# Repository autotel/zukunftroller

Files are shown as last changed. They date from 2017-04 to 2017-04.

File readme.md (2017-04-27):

#Building Controller shematic
##Pin allocation

Inputs/ outputs requeridos
```
                                1: 25 botones en circulo
                                  |  2: 11 botones de modo
                                  |  |  3: 2 terminales de led independientes
                                  |  |  |  4: 11 terminales independientes de led
                                  |  |  |  |  5: 3 terminales para controlar dos pantallas (clock,data,?)
                                  |  |  |  |  |  6: 12 encoder 12 estados
                                  |  |  |  |  |  |  7: 1 botón reset (usaremos el pin reset de arduino)
                                  |  |  |  |  |  |  |  8: 4 dos encoders de parámetro
                                  |  |  |  |  |  |  |  |  9: 2 pines display oLed sobre I2C
                                  |  |  |  |  |  |  |  |  |  10: 1 Midi out
                                  |  |  |  |  |  |  |  |  |  |  11: 1 Midi o serial in (para acoplar teclado melódico, que es un desarrollo aparte)
Pines de los multiplexores -------|--|--|--|--|--|--|--|--|--|--| --------------------------------------------------------------------------
                                  |  |  |  |  |  |  |  |  |  |  |  12: 8 MUX address
                                  |  |  |  |  |  |  |  |  |  |  |  |  13: 2 MUX Common
                                  |  |  |  |  |  |  |  |  |  |  |  |  |  14: 3 Shift register
... van conectados al pin...------|--|--|--|--|--|--|--|--|--|--|--|--|--|---------------------------------------------------------------------
                                  |  |  |  |  |  |  |  |  |  |  |  |  |  |    Total usado:
Directo arduino (18,+1 Tx)--------|--|--|--|--|--|--|--|--|--|--|--| 8| 2|--  | 10/18
Terminal Reset (1)----------------|--|--|--|--|--|--| 1|--|--|--|--|--|--|--  | 1/1
Multiplexor Directo (n=32)--------|--|--|--|--| 3|--|--| 4| 2| 1|--|--|--| 3  | 13/32
Multiplexor en Matrix (256-n^2)---|25|11|--|--|--|12|--|--|--|--|--|--|--|--  | 48/(256-13^2)
Puerto serial in Arduino (1)------|--|--|--|--|--|--|--|--|--|--| 1|--|--|--  | 1/1
Shift register (8 o 16)-----------|--|--| 2|11|--|--|--|--|--|--|--|--|--|--  | 13/16
```

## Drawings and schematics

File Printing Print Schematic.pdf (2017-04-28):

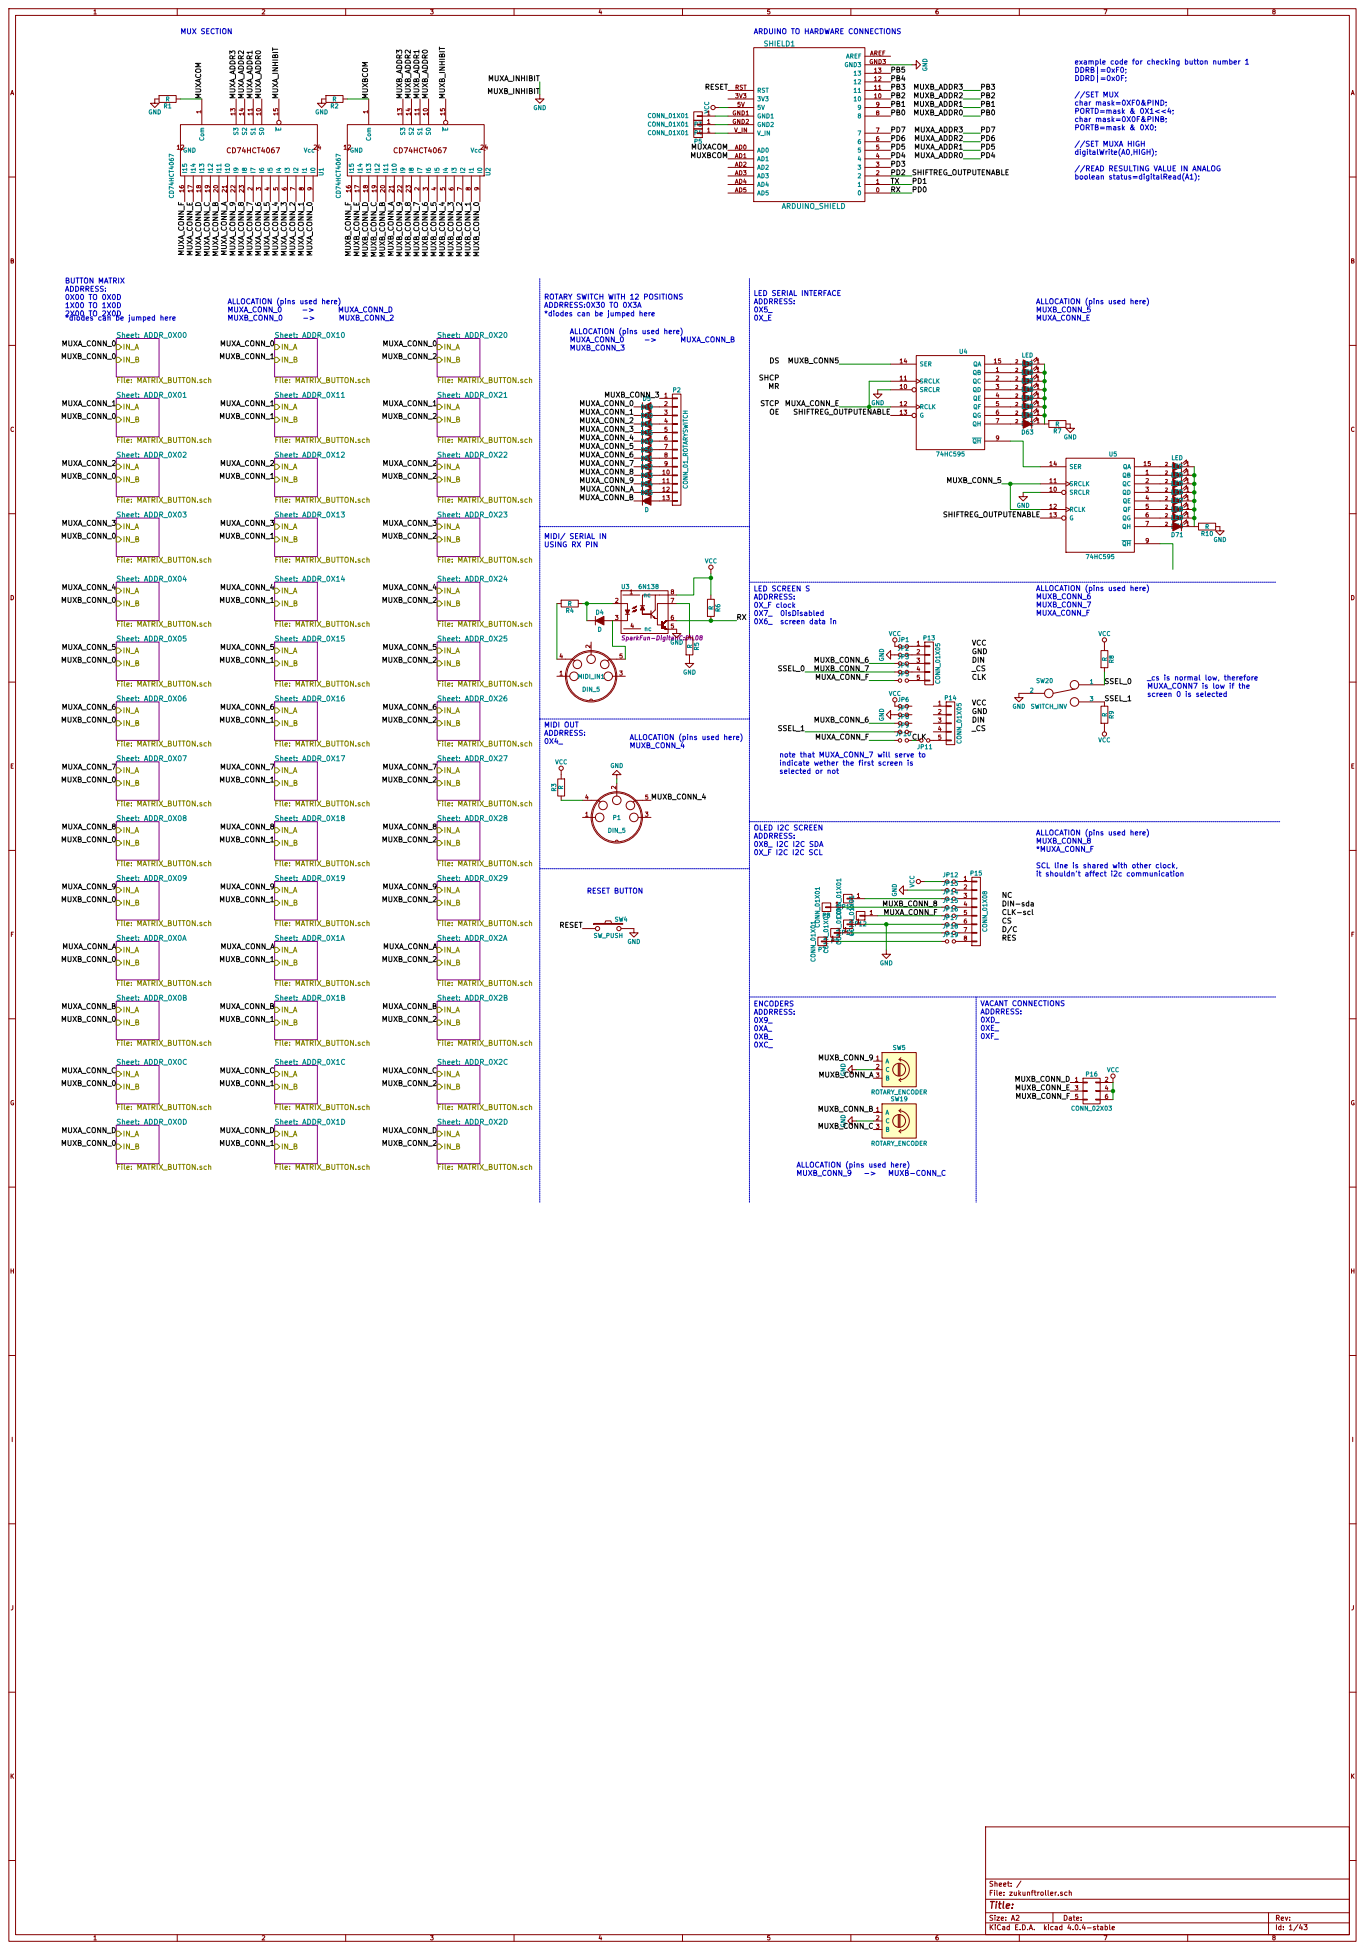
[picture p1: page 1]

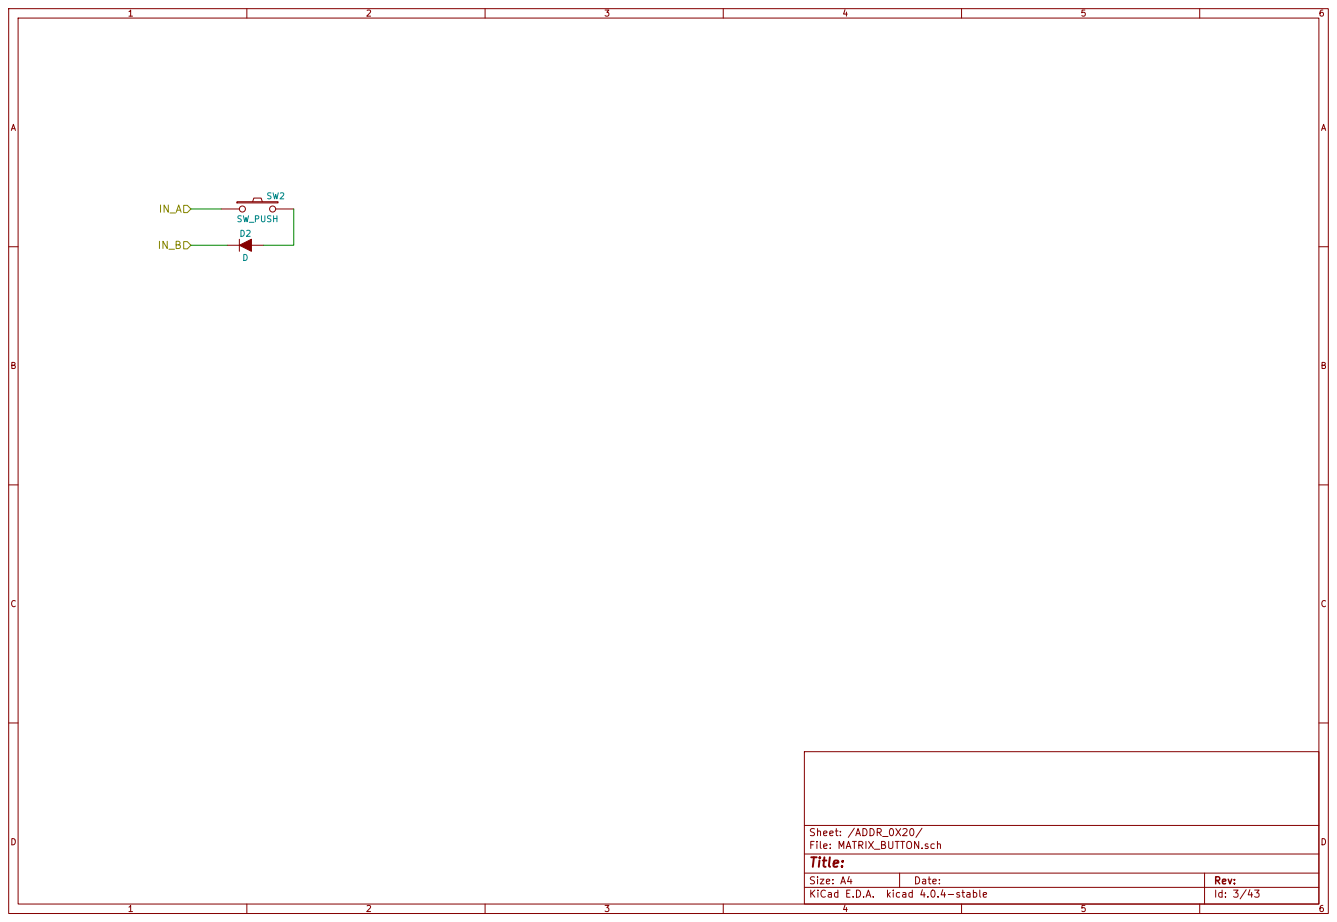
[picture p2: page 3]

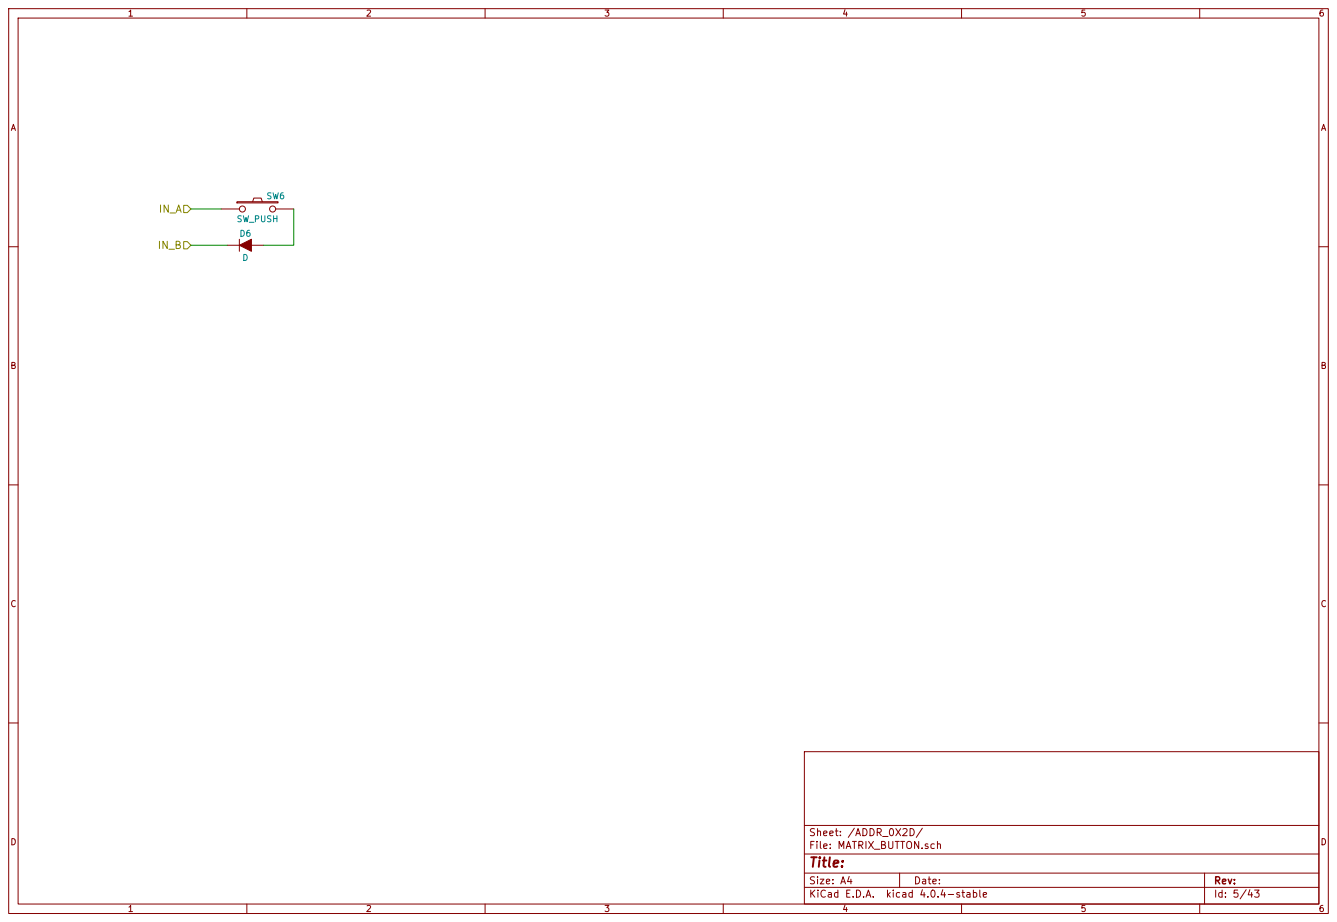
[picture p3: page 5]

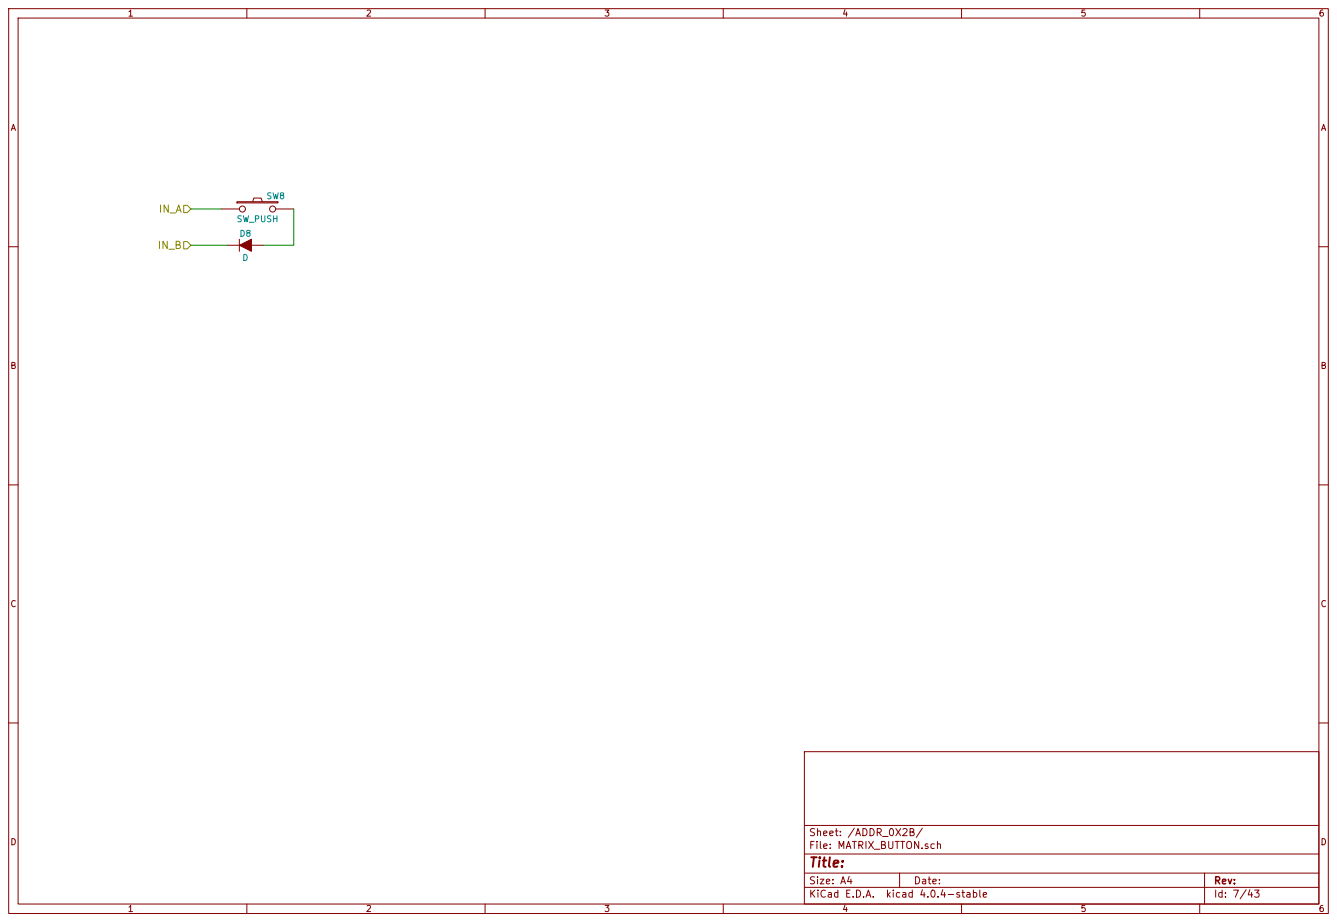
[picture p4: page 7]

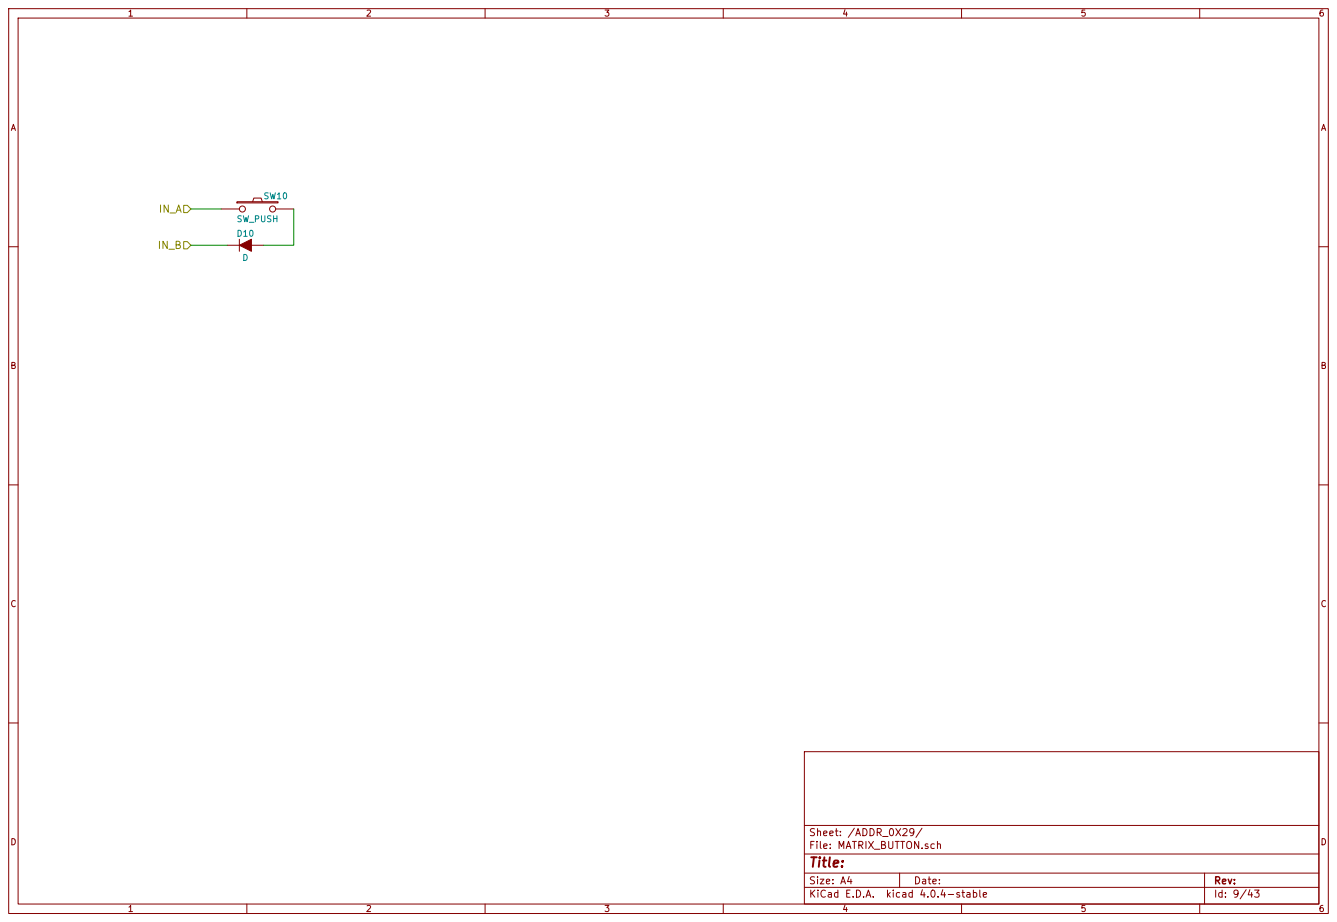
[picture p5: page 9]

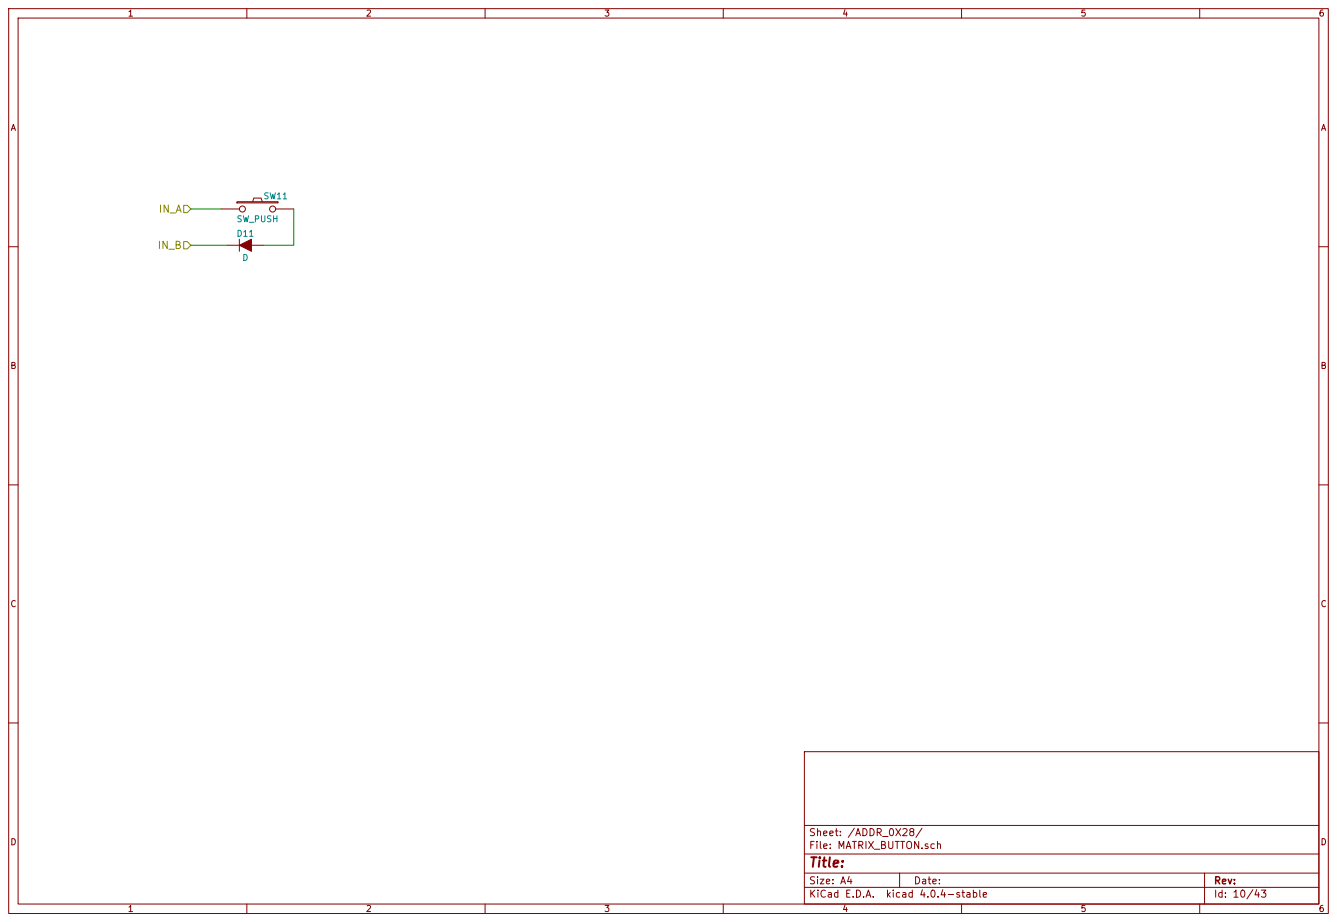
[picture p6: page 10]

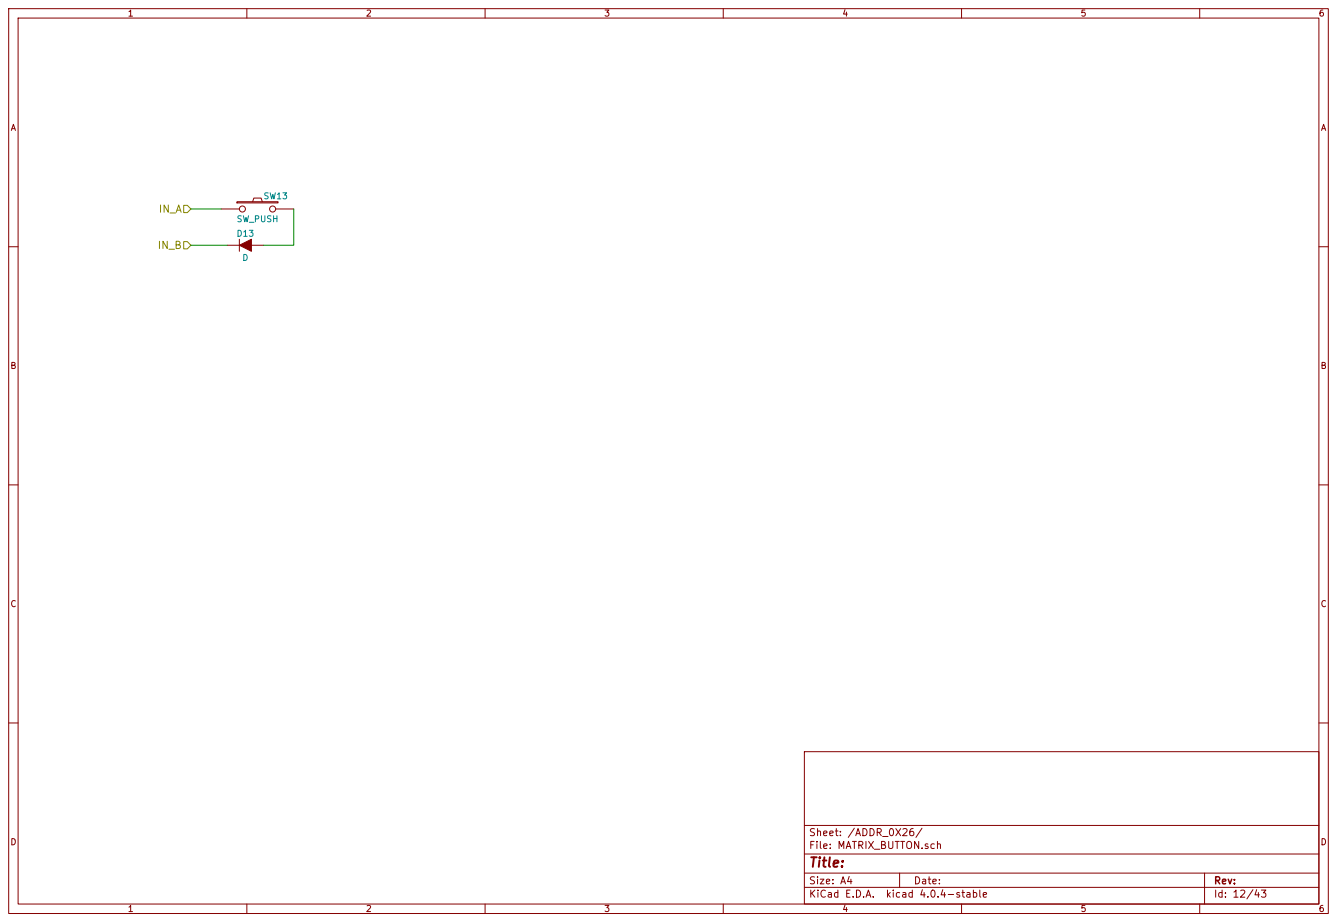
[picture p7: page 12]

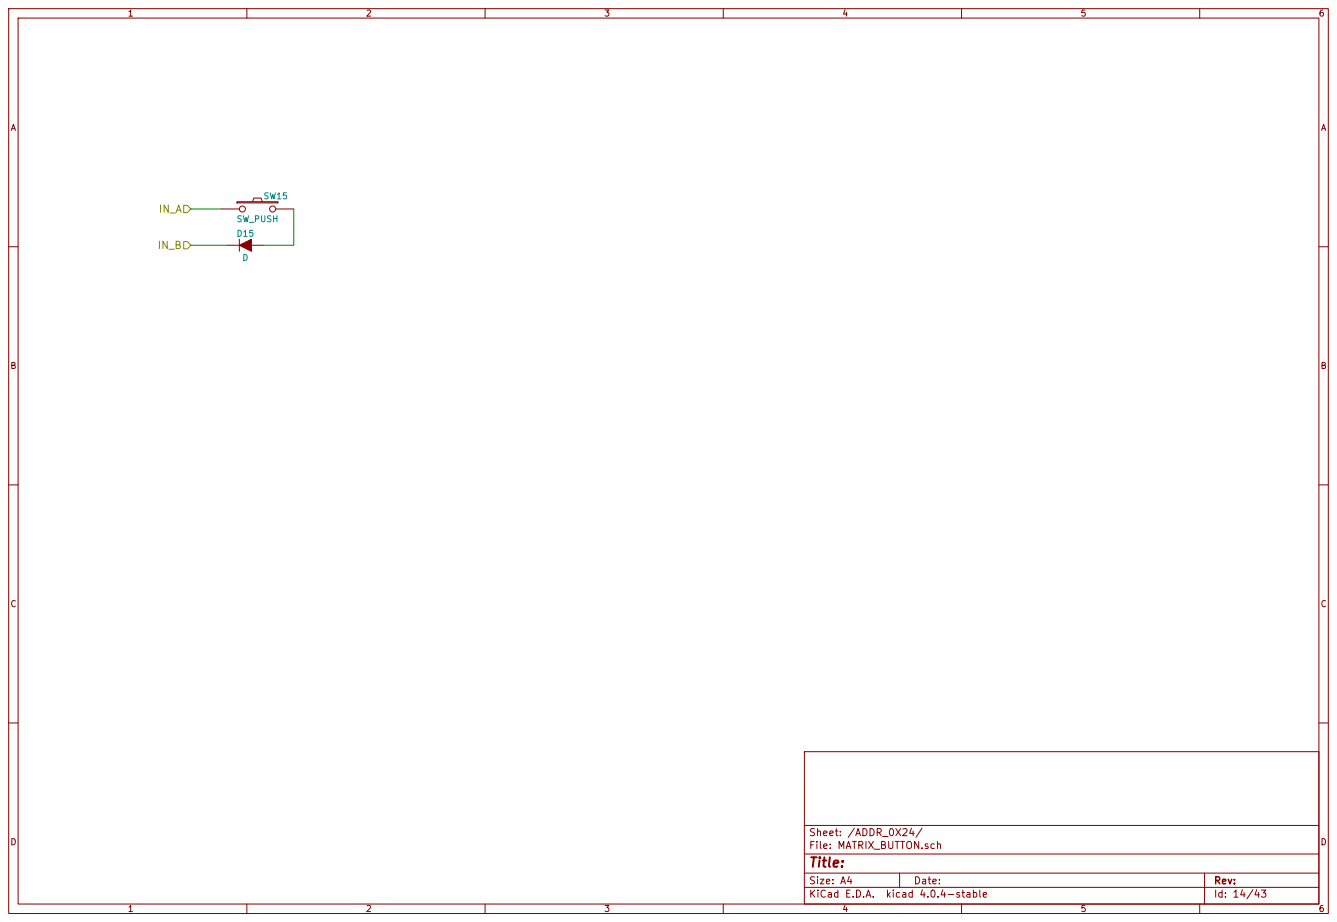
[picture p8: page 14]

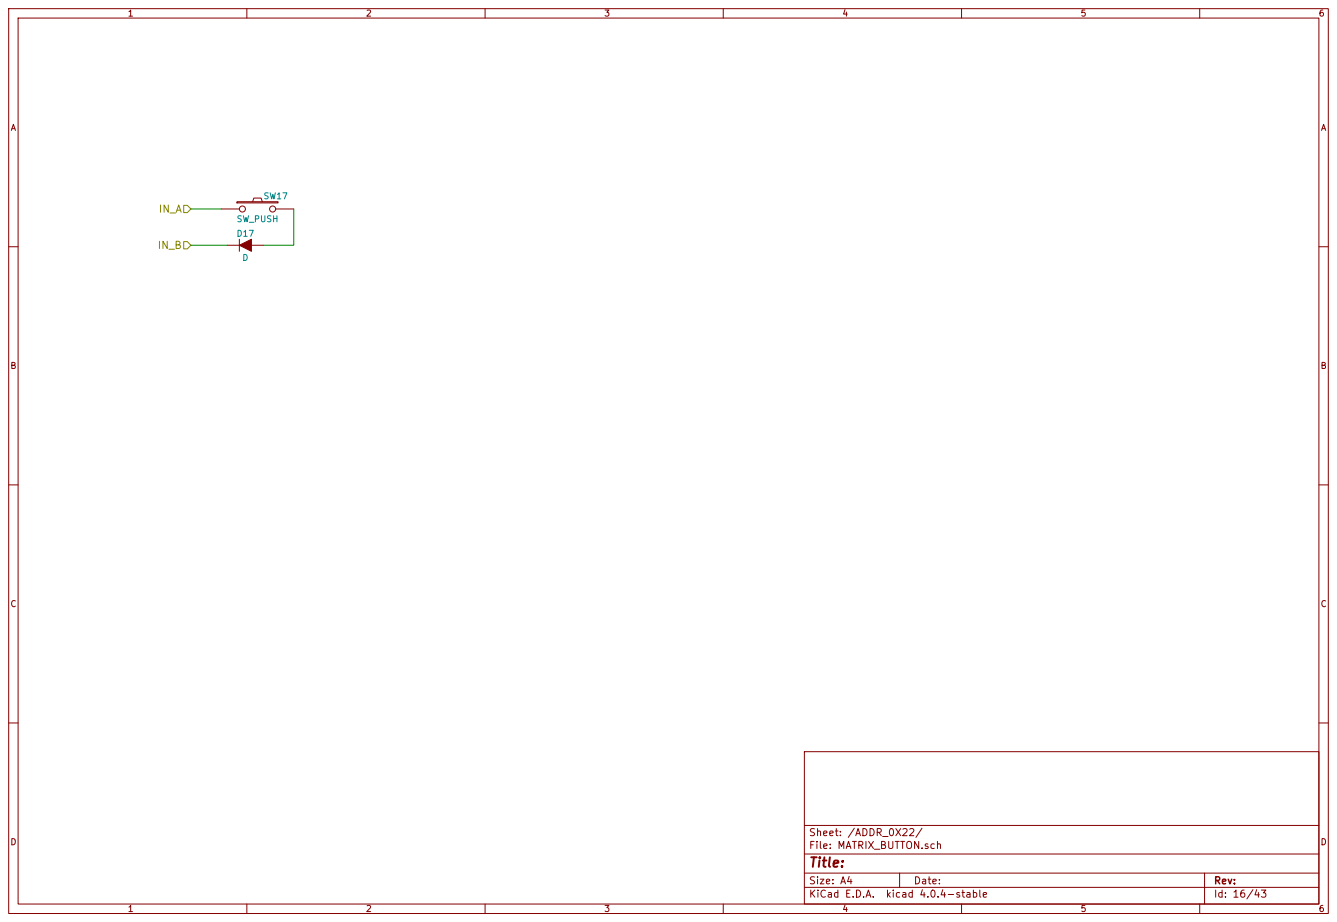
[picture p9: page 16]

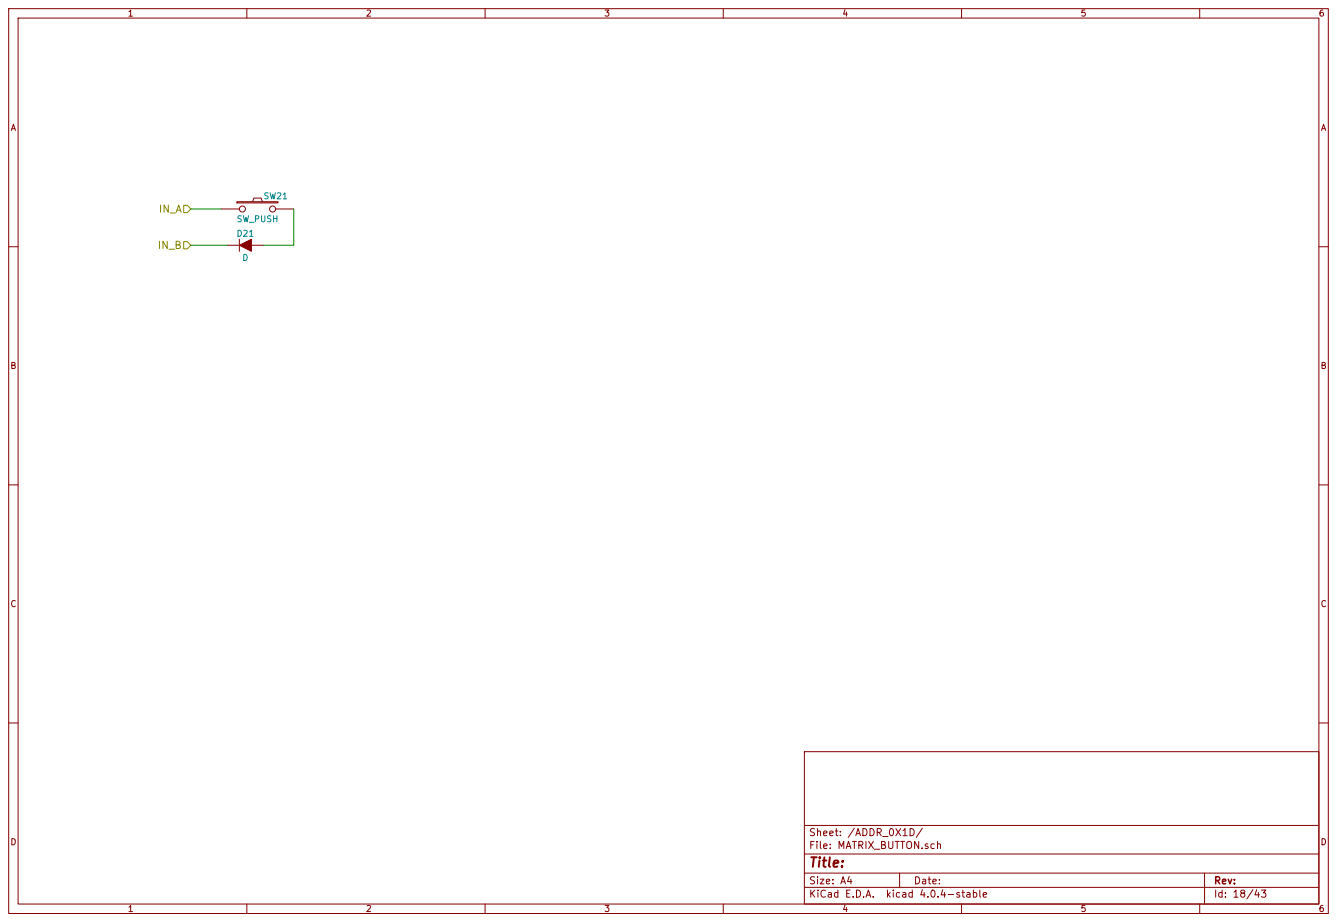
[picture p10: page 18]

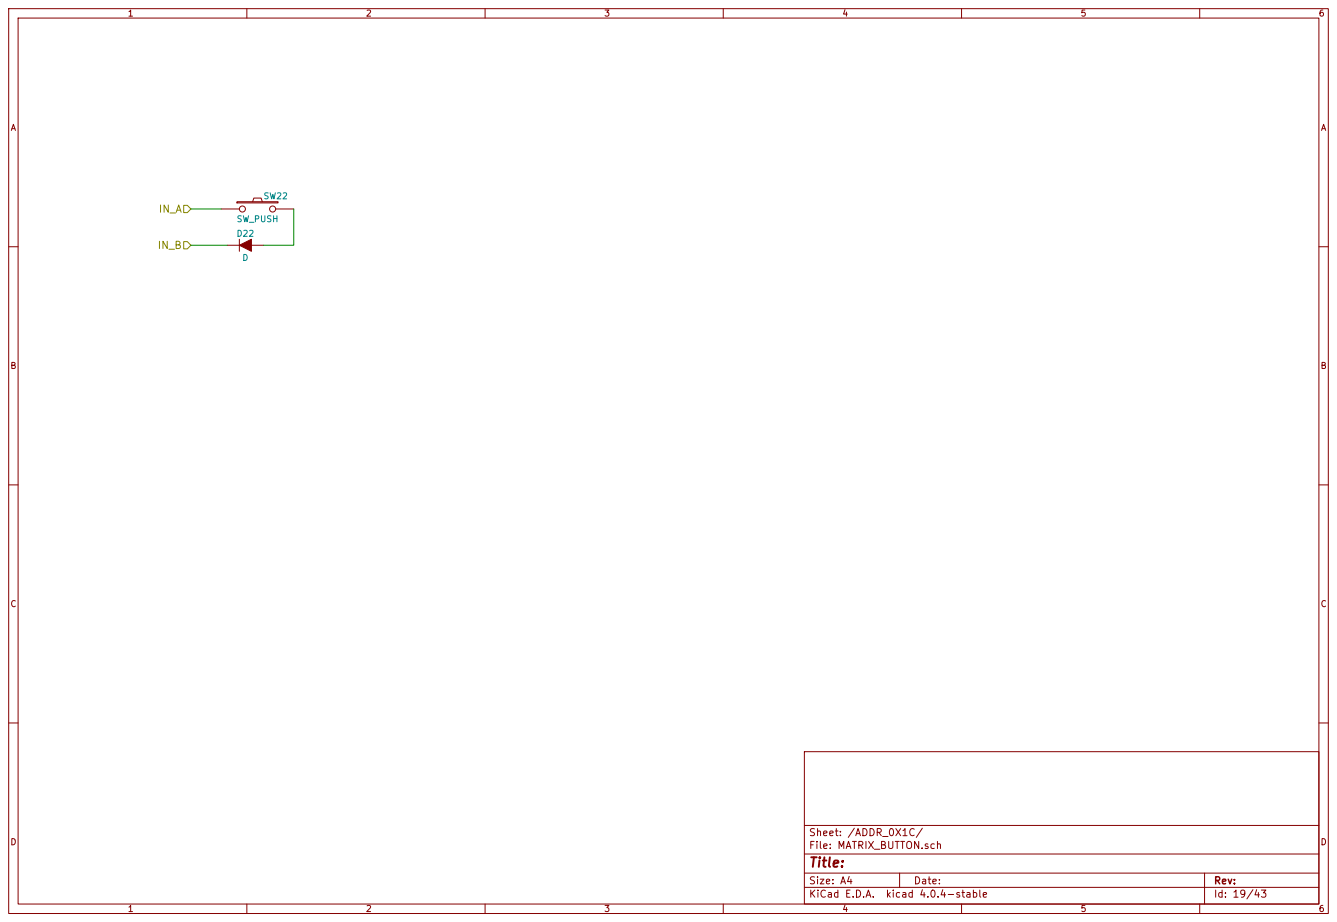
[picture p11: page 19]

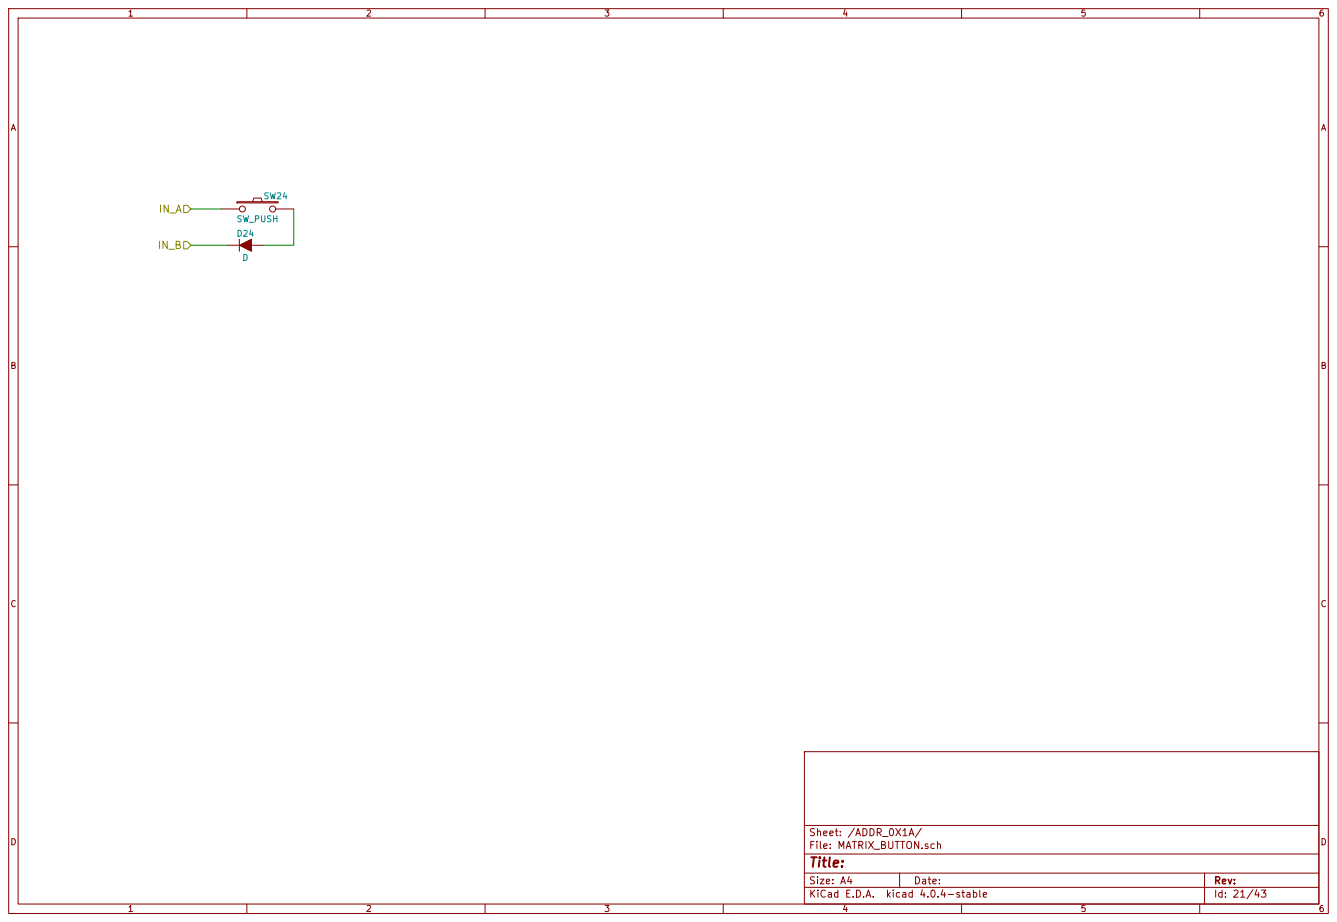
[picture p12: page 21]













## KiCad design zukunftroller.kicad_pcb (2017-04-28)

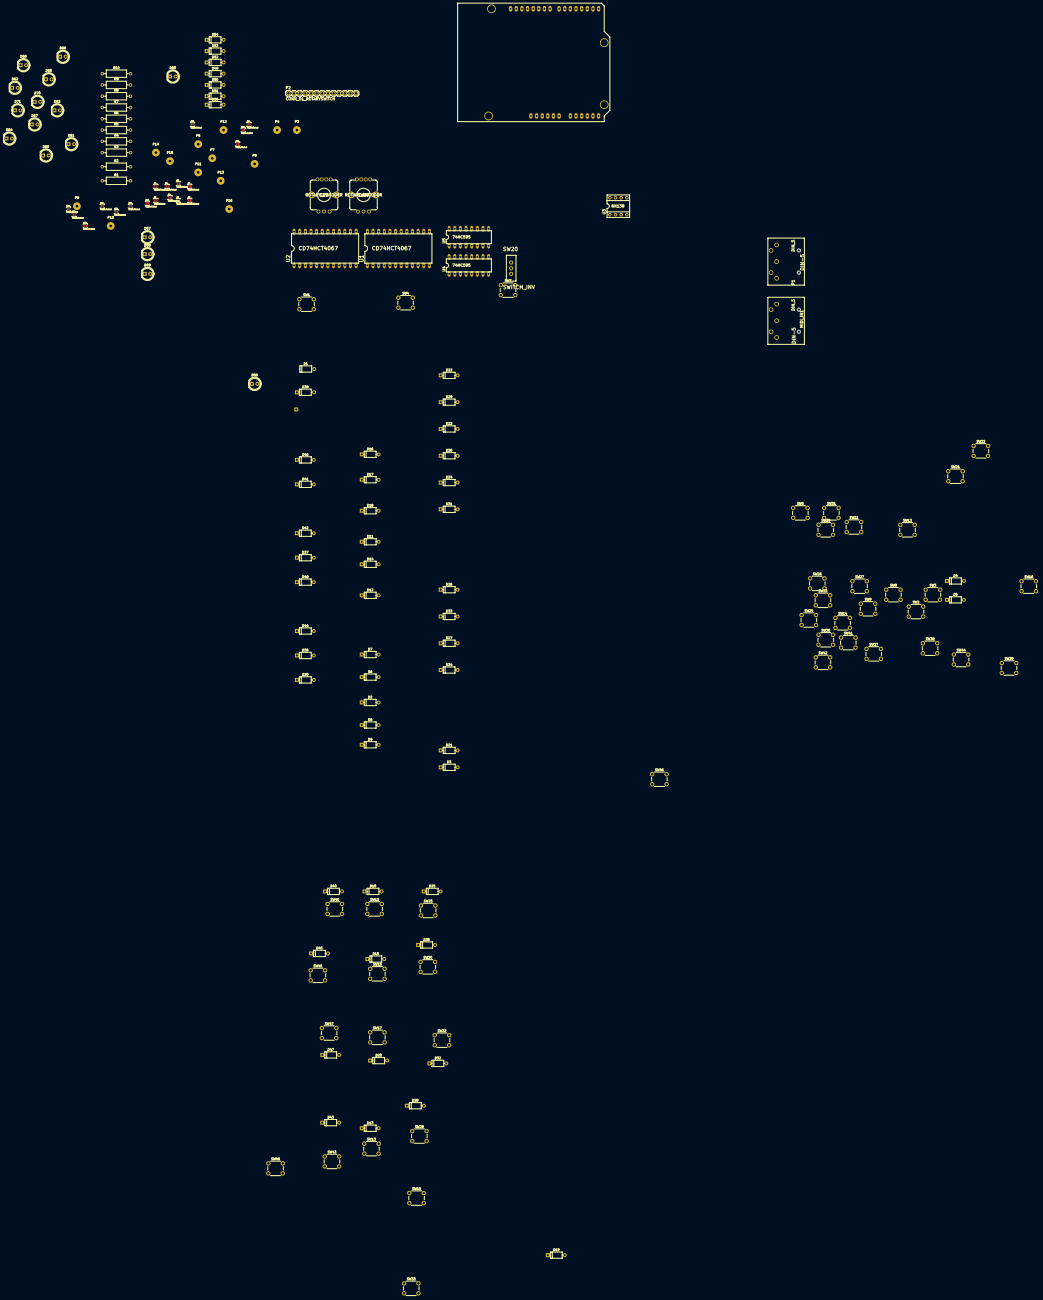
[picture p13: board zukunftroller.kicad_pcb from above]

Board: 2 copper layers, 168 parts (0 on the bottom side), 129 nets, no tracks yet.

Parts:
D1, D2, D3, D4, D5, D6, D7, D8, D9, D10, D11, D12, D13, D14, D15, D16, D17, D18, D19, D20, D21, D22, D23, D24, D25, D26, D27, D28, D29, D30, D31, D32, D33, D34, D35, D36, D37, D38, D39, D40, D41, D42, D43, D44, D45, D46, D47, D48, D49, D50, D51, D52, D53, D54, D55: D; D_A-405_P7.62mm_Horizontal
D56, D57, D58, D59, D60, D61, D62, D63, D64, D65, D66, D67, D68, D69, D70, D71: LED; LED_D5.0mm
JP1, JP2, JP3, JP4, JP5, JP6, JP7, JP8, JP9, JP10, JP11, JP12, JP13, JP14, JP15, JP16, JP17, JP18, JP19: Jumper_NO_Small; PAD-JUMPER-2-NO_YES_SILK
MIDI_IN1: DIN_5; DIN_5_FEMALE
P1: DIN_5; DIN_5_FEMALE
P2: CONN_01_ROTARYSWITCH; 1X13
P3, P4, P5, P7, P8, P9, P10, P11, P12: CONN_01X01; SolderWirePad_single_1-2mmDrill
P13, P14: CONN_01X05; SolderWirePad_single_1-2mmDrill
P15: CONN_01X08; SolderWirePad_single_1-2mmDrill
P16: CONN_02X03; SolderWirePad_single_1-2mmDrill
R1, R2, R3, R4, R5, R6, R7, R8, R9, R10: R; R_Axial_DIN0309_L9.0mm_D3.2mm_P12.70mm_Horizontal
SHIELD1: ARDUINO_SHIELD; ARDUINO SHIELD
SW1, SW2, SW3, SW4, SW6, SW7, SW8, SW9, SW10, SW11, SW12, SW13, SW14, SW15, SW16, SW17, SW18, SW21, SW22, SW23, SW24, SW25, SW26, SW27, SW28, SW29, SW30, SW31, SW32, SW33, SW36, SW37, SW38, SW39, SW40, SW41, SW42, SW43, SW44, SW45, SW46, SW47, SW48: SW_PUSH; SW_PUSH_6mm
SW5, SW19: ROTARY_ENCODER; ENCODER_LED_2
SW20: SWITCH_INV; SWITCH-SPDT
U1, U2: CD74HCT4067; DIL24-6
U3: 6N138; DIL08
U4, U5: 74HC595; DIL16

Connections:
/CLK: JP10.2, JP11.2
/MUXACOM: R1.1, SHIELD1.AD0, U1.1
/MUXA_ADDR0: SHIELD1.4, U1.10
/MUXA_ADDR1: SHIELD1.5, U1.11
/MUXA_ADDR2: SHIELD1.6, U1.14
/MUXA_ADDR3: SHIELD1.7, U1.13
/MUXA_CONN_0: D5.1, SW1.1, SW2.1, SW3.1, U1.9
/MUXA_CONN_1: D19.1, SW18.1, SW33.1, SW48.1, U1.8
/MUXA_CONN_2: D20.1, SW17.1, SW32.1, SW47.1, U1.7
/MUXA_CONN_3: D34.1, SW16.1, SW31.1, SW46.1, U1.6
/MUXA_CONN_4: D35.1, SW15.1, SW30.1, SW45.1, U1.5
/MUXA_CONN_5: D49.1, SW14.1, SW29.1, SW44.1, U1.4
/MUXA_CONN_6: D50.1, SW13.1, SW28.1, SW43.1, U1.3
/MUXA_CONN_7: D51.1, SW12.1, SW27.1, SW42.1, U1.2
/MUXA_CONN_8: D52.1, SW11.1, SW26.1, SW41.1, U1.23
/MUXA_CONN_9: D53.1, SW10.1, SW25.1, SW40.1, U1.22
/MUXA_CONN_A: D54.1, SW9.1, SW24.1, SW39.1, U1.21
/MUXA_CONN_B: D55.1, SW8.1, SW23.1, SW38.1, U1.20
/MUXA_CONN_C: SW7.1, SW22.1, SW37.1, U1.19
/MUXA_CONN_D: SW6.1, SW21.1, SW36.1, U1.18
/MUXA_CONN_E: U1.17, U4.11, U4.12
/MUXA_CONN_F: JP5.1, JP10.1, JP16.1, P12.1, U1.16
/MUXBCOM: R2.1, SHIELD1.AD1, U2.1
/MUXB_ADDR0: SHIELD1.8, U2.10
/MUXB_ADDR1: SHIELD1.9, U2.11
/MUXB_ADDR2: SHIELD1.10, U2.14
/MUXB_ADDR3: SHIELD1.11, U2.13
/MUXB_CONN_0: D1.1, D36.1, D37.1, D38.1, D39.1, D40.1, D41.1, D42.1, D43.1, D44.1, D45.1, D46.1, D47.1, D48.1, U2.9
/MUXB_CONN_1: D3.1, D21.1, D22.1, D23.1, D24.1, D25.1, D26.1, D27.1, D28.1, D29.1, D30.1, D31.1, D32.1, D33.1, U2.8
/MUXB_CONN_2: D2.1, D6.1, D7.1, D8.1, D9.1, D10.1, D11.1, D12.1, D13.1, D14.1, D15.1, D16.1, D17.1, D18.1, U2.7
/MUXB_CONN_3: P2.1, U2.6
/MUXB_CONN_4: P1.5, U2.5
/MUXB_CONN_5: U2.4, U5.11, U5.12
/MUXB_CONN_6: JP3.1, JP8.1, U2.3
/MUXB_CONN_7: JP4.1, R8.2, SW20.1, U2.2
/MUXB_CONN_8: JP15.1, P8.1, U2.23
/MUXB_CONN_D: P16.1, U2.18
/PD0: R6.2, SHIELD1.0, U3.6
/PD2: SHIELD1.2, U4.13, U5.13
/RESET: SHIELD1.RST, SW4.1
/SSEL_1: JP9.1, R9.1, SW20.3
GND: JP2.1, JP7.1, JP13.1, JP17.1, P1.2, P11.1, R1.2, R2.2, R5.2, R7.1, R10.1, SHIELD1.GND3, SW4.2, SW20.2, U1.15, U2.15, U3.5, U4.8, U4.10, U5.8, U5.10
unnamed: D1.2, SW1.2
unnamed: D2.2, SW2.2
unnamed: D3.2, SW3.2
unnamed: D4.1, R4.1, U3.2
unnamed: D4.2, MIDI_IN1.5, U3.3
unnamed: D5.2, P2.2
unnamed: D6.2, SW6.2
unnamed: D7.2, SW7.2
unnamed: D8.2, SW8.2
unnamed: D9.2, SW9.2
unnamed: D10.2, SW10.2
unnamed: D11.2, SW11.2
unnamed: D12.2, SW12.2
unnamed: D13.2, SW13.2
unnamed: D14.2, SW14.2
unnamed: D15.2, SW15.2
unnamed: D16.2, SW16.2
unnamed: D17.2, SW17.2
unnamed: D18.2, SW18.2
unnamed: D19.2, P2.3
unnamed: D20.2, P2.4
unnamed: D21.2, SW21.2
unnamed: D22.2, SW22.2
unnamed: D23.2, SW23.2
unnamed: D24.2, SW24.2
unnamed: D25.2, SW25.2
unnamed: D26.2, SW26.2
unnamed: D27.2, SW27.2
unnamed: D28.2, SW28.2
unnamed: D29.2, SW29.2
unnamed: D30.2, SW30.2
unnamed: D31.2, SW31.2
unnamed: D32.2, SW32.2
unnamed: D33.2, SW33.2
unnamed: D34.2, P2.5
unnamed: D35.2, P2.6
unnamed: D36.2, SW36.2
unnamed: D37.2, SW37.2
unnamed: D38.2, SW38.2
unnamed: D39.2, SW39.2
unnamed: D40.2, SW40.2
unnamed: D41.2, SW41.2
unnamed: D42.2, SW42.2
unnamed: D43.2, SW43.2
unnamed: D44.2, SW44.2
unnamed: D45.2, SW45.2
unnamed: D46.2, SW46.2
unnamed: D47.2, SW47.2
unnamed: D48.2, SW48.2
unnamed: D49.2, P2.7
unnamed: D50.2, P2.8
unnamed: D51.2, P2.9
unnamed: D52.2, P2.10
unnamed: D53.2, P2.11
unnamed: D54.2, P2.12
unnamed: D55.2, P2.13
unnamed: D56.1, D57.1, D58.1, D59.1, D60.1, D61.1, D62.1, D63.1, R7.2
unnamed: D56.2, U4.15
unnamed: D57.2, U4.1
unnamed: D58.2, U4.2
unnamed: D59.2, U4.3
unnamed: D60.2, U4.4
unnamed: D61.2, U4.5
unnamed: D62.2, U4.6
unnamed: D63.2, U4.7
unnamed: D64.1, D65.1, D66.1, D67.1, D68.1, D69.1, D70.1, D71.1, R10.2
unnamed: D64.2, U5.15
unnamed: D65.2, U5.1
unnamed: D66.2, U5.2
unnamed: D67.2, U5.3
unnamed: D68.2, U5.4
unnamed: D69.2, U5.5
unnamed: D70.2, U5.6
unnamed: D71.2, U5.7
unnamed: JP1.2, P13.1
unnamed: JP12.2, P15.1
unnamed: JP14.1, P10.1
unnamed: JP18.1, P9.1
unnamed: JP19.1, P7.1
unnamed: MIDI_IN1.4, R4.2
unnamed: P1.4, R3.1
unnamed: P3.1, SHIELD1.GND1
unnamed: P4.1, SHIELD1.GND2
unnamed: P5.1, SHIELD1.V_IN
unnamed: R5.1, U3.7
unnamed: U4.9, U5.14
VCC: JP1.1, JP6.1, JP12.1, R3.2, R6.1, R8.1, R9.2, SHIELD1.5V, U3.8, U4.16, U5.16

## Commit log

2017-04-27 start creating shcematic
    [zukunftroller.kicad_pcb, zukunftroller.sch]
2017-04-27 name mux output and create button block
    [ADDR_0X00.sch, MUX_CONN_X.sch, zukunftroller.sch]
2017-04-27 array of buttons in blocks
    [MATRIX_BUTTON.sch, MUX_CONN_X.sch, zukunftroller.sch]
2017-04-27 planned pin allocation
2017-04-27 button matrix
    [MATRIX_BUTTON.sch, zukunftroller.sch]
2017-04-27 -changes in pin allocation -most of the wiring
    [MATRIX_BUTTON.sch, zukunftroller.kicad_pcb, zukunftroller.sch]
2017-04-27 rename readme
    [zukunftroller.sch]
2017-04-27 fixed some wrong pin connections
    [zukunftroller.sch]
2017-04-27 fixed a couple more of wrong pins & additional notes
    [zukunftroller.sch]
2017-04-27 mux inhibit to ground
    [zukunftroller.sch]
2017-04-27 comment: example code (not tested)
    [zukunftroller.sch]
2017-04-28 added jumpers in case of error
    [zukunftroller.sch]
2017-04-28 pins for vacant mux connections
    [zukunftroller.sch]
2017-04-28 pull down resistors in mux commons
    [zukunftroller.sch]
2017-04-28 resistor for leds in shoft register
    [zukunftroller.sch]
2017-04-28 assigned footprints, in process of scattering elements in pcb
    [MATRIX_BUTTON.sch, zukunftroller.kicad_pcb, zukunftroller.sch]
2017-04-28 sorting buttons, changed footprint of 4067
    [zukunftroller.kicad_pcb, zukunftroller.sch]
2017-04-28 more sorting
    [zukunftroller.kicad_pcb]
